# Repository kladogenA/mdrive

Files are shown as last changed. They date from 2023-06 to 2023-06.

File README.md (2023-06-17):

# mdrive
A microdrive emulator for the Sinclair QL based on Raspberry Pico and an SD card reader.

This project aims to create a standalone microdive emulator for the Sinclair QL with an OLED screen, SD card reader and buttons used to selected the MDV image to make available to the QL.
It employs a Raspberry Pico that communicates with the QL through an 74LS125 line buffer for the Tracks and diodes for the rest of the pins.
This project is in a preliminary stage, partialy working.

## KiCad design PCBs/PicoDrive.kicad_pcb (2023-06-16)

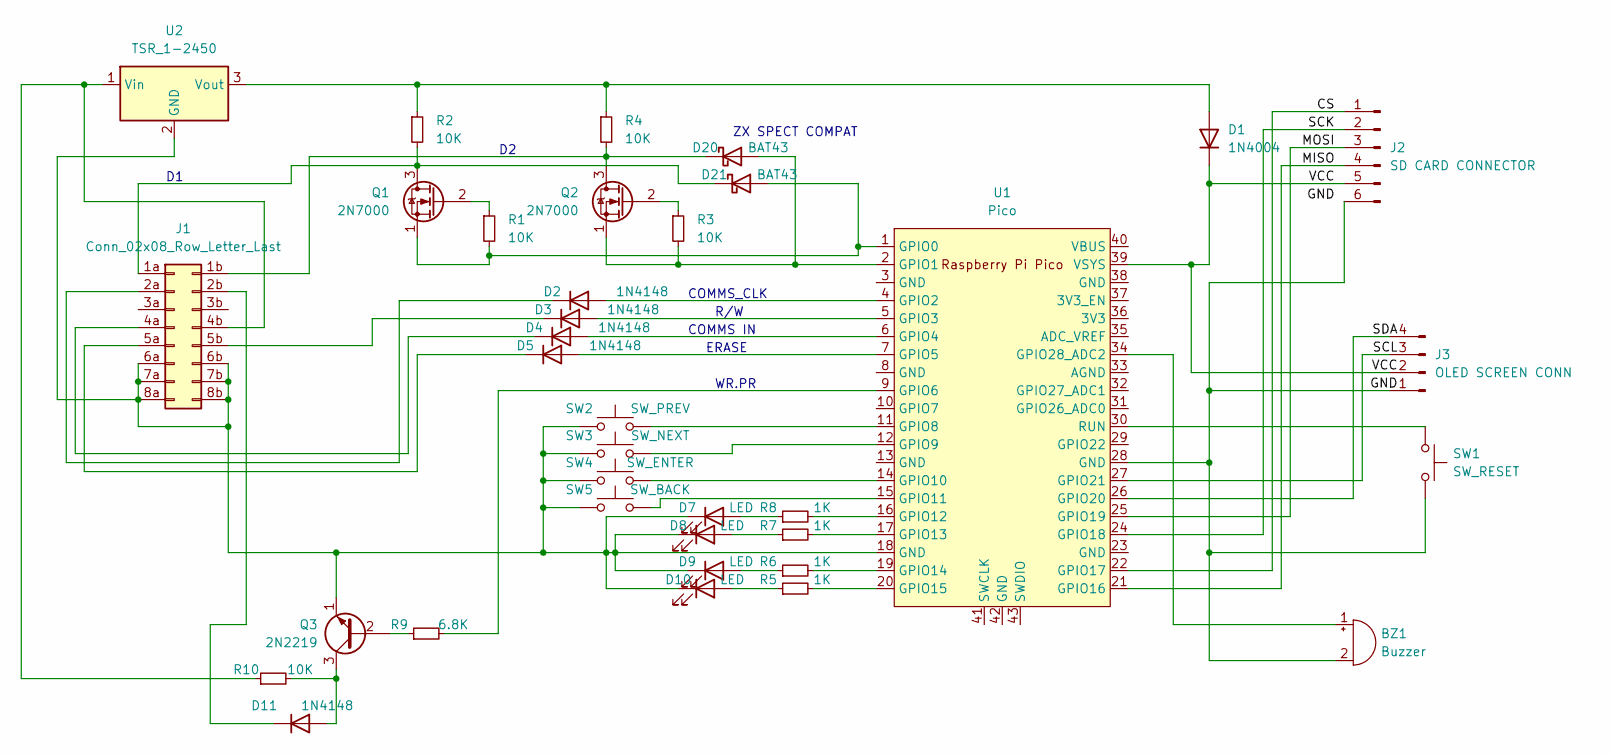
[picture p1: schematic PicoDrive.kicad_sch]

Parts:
BZ1: Buzzer; Buzzer_12x9.5RM7.6
D1: 1N4004; D_DO-41_SOD81_P10.16mm_Horizontal
D2, D3, D4, D5: 1N4148; D_DO-41_SOD81_P10.16mm_Horizontal
D7, D8, D9, D10: LED; LED_D3.0mm
D11: 1N4148; D_DO-35_SOD27_P7.62mm_Horizontal
D20, D21: BAT43; D_DO-35_SOD27_P7.62mm_Horizontal
J1: Conn_02x08_Row_Letter_Last; PinHeader_2x08_P2.54mm_Vertical_letters
J2: SD CARD CONNECTOR; PinHeader_1x06_P2.54mm_Vertical
J3: OLED SCREEN CONN; PinHeader_1x04_P2.54mm_Vertical
Q1, Q2: 2N7000; TO-92_Inline
Q3: 2N2219; TO-18-3
R1, R2, R3, R4, R10: 10K; R_Axial_DIN0204_L3.6mm_D1.6mm_P7.62mm_Horizontal
R5, R6, R7, R8: 1K; R_Axial_DIN0204_L3.6mm_D1.6mm_P7.62mm_Horizontal
R9: 6.8K; R_Axial_DIN0204_L3.6mm_D1.6mm_P7.62mm_Horizontal
SW1: SW_RESET; SW_PUSH_6mm
SW2: SW_PREV; SW_PUSH_6mm
SW3: SW_NEXT; SW_PUSH_6mm
SW4: SW_ENTER; SW_PUSH_6mm
SW5: SW_BACK; SW_PUSH_6mm
U1: Pico; RPi_Pico_SMD_TH
U2: TSR_1-2450; Converter_DCDC_TRACO_TSR-1_THT

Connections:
/CS: J2.1, U1.22 (GPIO17)
/MISO: J2.4, U1.21 (GPIO16)
/MOSI: J2.3, U1.25 (GPIO19)
/SCK: J2.2, U1.24 (GPIO18)
/VCC: D1.1 (K), J2.5, J3.2, U1.39 (VSYS)
unnamed: BZ1.1 (-), U1.34 (GPIO28_ADC2)
unnamed: D1.2 (A), R2.1, R4.1, U2.3 (Vout)
unnamed: D2.1 (K), J1.2a
unnamed: D2.2 (A), U1.4 (GPIO2)
unnamed: D3.1 (K), J1.5b
unnamed: D3.2 (A), U1.5 (GPIO3)
unnamed: D4.1 (K), J1.4a
unnamed: D4.2 (A), U1.6 (GPIO4)
unnamed: D5.1 (K), J1.5a
unnamed: D5.2 (A), U1.7 (GPIO5)
unnamed: D7.2 (A), R8.1
unnamed: D8.2 (A), R7.1
unnamed: D9.2 (A), R6.1
unnamed: D7.1 (K), D8.1 (K), D9.1 (K), D10.1 (K), J1.6a, J1.6b, J1.7a, J1.7b, J1.8a, J1.8b, Q3.1 (E), SW2.1, SW3.1, SW4.1, SW5.1, U1.18 (GND), U2.2 (GND)
unnamed: D10.2 (A), R5.1
unnamed: D11.1 (K), J1.2b
unnamed: D11.2 (A), Q3.3 (C), R10.2
unnamed: D20.1 (K), J1.1b, Q2.3 (D), R4.2
unnamed: D20.2 (A), Q2.1 (S), R3.2, U1.2 (GPIO1)
unnamed: D21.1 (K), J1.1a, Q1.3 (D), R2.2
unnamed: D21.2 (A), Q1.1 (S), R1.2, U1.1 (GPIO0)
unnamed: J1.4b, R10.1, U2.1 (Vin)
unnamed: BZ1.2 (+), J2.6, J3.1, SW1.2, U1.28 (GND)
unnamed: J3.3, U1.27 (GPIO21)
unnamed: J3.4, U1.26 (GPIO20)
unnamed: Q1.2 (G), R1.1
unnamed: Q2.2 (G), R3.1
unnamed: Q3.2 (B), R9.1
unnamed: R5.2, U1.20 (GPIO15)
unnamed: R6.2, U1.19 (GPIO14)
unnamed: R7.2, U1.17 (GPIO13)
unnamed: R8.2, U1.16 (GPIO12)
unnamed: R9.2, U1.9 (GPIO6)
unnamed: SW1.1, U1.30 (RUN)
unnamed: SW2.2, U1.11 (GPIO8)
unnamed: SW3.2, U1.12 (GPIO9)
unnamed: SW4.2, U1.14 (GPIO10)
unnamed: SW5.2, U1.15 (GPIO11)

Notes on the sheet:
R/W
ERASE
ZX SPECT COMPAT
COMMS_CLK
COMMS IN
WR.PR

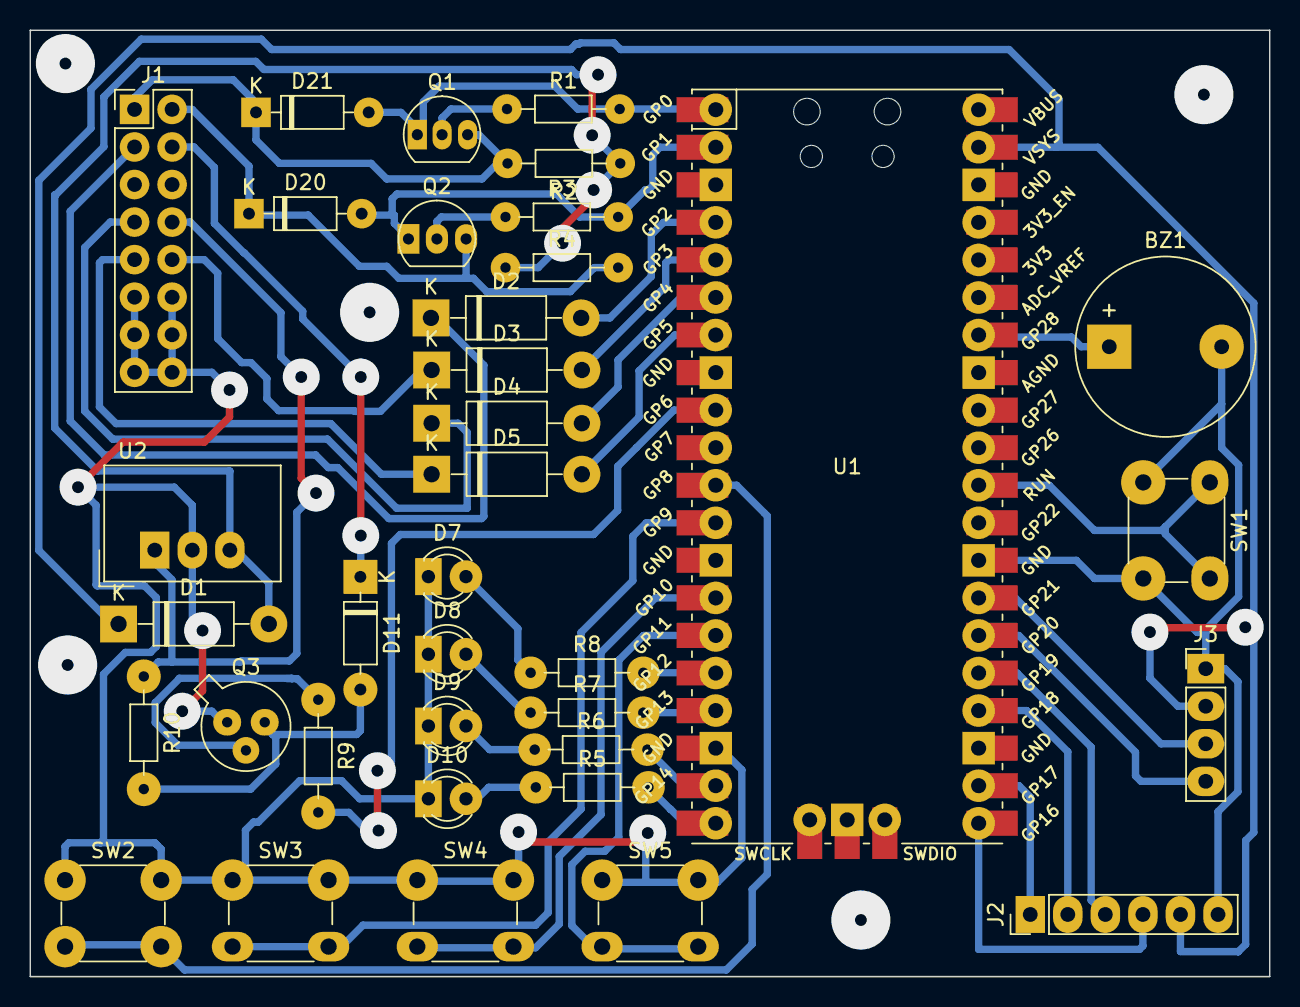
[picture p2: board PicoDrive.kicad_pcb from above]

Board: 2 copper layers, 83.8 x 64.0 mm, 36 parts (0 on the bottom side), 43 nets.

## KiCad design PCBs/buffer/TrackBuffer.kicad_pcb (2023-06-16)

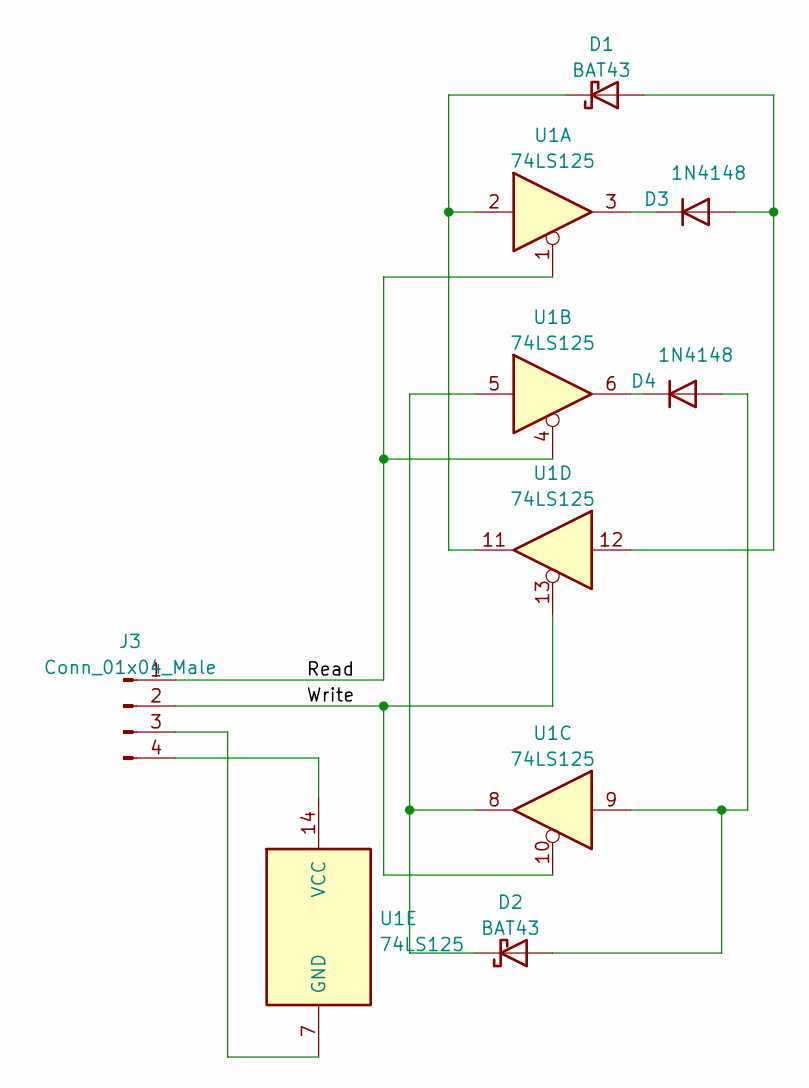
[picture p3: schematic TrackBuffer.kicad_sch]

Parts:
D1, D2: BAT43; D_DO-35_SOD27_P7.62mm_Horizontal
D3, D4: 1N4148; D_T-1_P5.08mm_Horizontal
J3: Conn_01x04_Male; PinHeader_1x04_P2.54mm_Vertical
U1: 74LS125

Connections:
/Read: J3.1, U1.1, U1.4
/Write: J3.2, U1.10, U1.13
unnamed: D2.1 (K), U1.5, U1.8
unnamed: D2.2 (A), D4.2 (A), U1.9
unnamed: D1.2 (A), D3.2 (A), U1.12
unnamed: J3.3, U1.7 (GND)
unnamed: J3.4, U1.14 (VCC)
unnamed: D3.1 (K), U1.3
unnamed: D4.1 (K), U1.6
unnamed: D1.1 (K), U1.2, U1.11

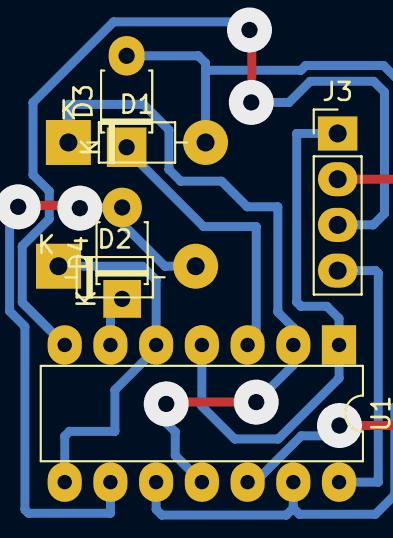
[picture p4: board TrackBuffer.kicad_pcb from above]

Board: 2 copper layers, 6 parts (0 on the bottom side), 10 nets.

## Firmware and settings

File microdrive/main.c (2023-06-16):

#include <stdio.h>
#include <stdlib.h>
#include <ctype.h>
#include "pico/stdlib.h"
#include <string.h>
#include "sd_card.h"
#include "ff.h"
#include "ff_stdio.h"

typedef unsigned char byte;

/*
1A -> GPIO0 TRACK1
1B -> GPIO1 TRACK2 
2A -> GPIO2 COMMS_CLK
2B -> GPIO6 WR.PR
3A -> NC
3B -> NC
4A -> GPIO4 COMMS_IN
4B -> U2 9V
5A -> GPIO5 ERASE
5B -> GPIO3 R/W ON TEST QL Read High is 2.2V so connected directly without voltage divider
6A -> GND
6B -> GND
7A -> GND
7B -> GNDCOMMS_CLKLED
8A -> GND
*/

#define QL_SECTOR_SIZE          686
#define QL_HEADER_SIZE          28          // 28
#define QL_BLOCK_SIZE           538         // 12 PREAMBLE + 2 HEADER + 2 CHECKSUM + 8 PREAMBLE + 512 DATA + 2 CHECKSUM = 538 DATA LENGTH
#define QL_EXTRA_DATA           86          // 84 bytes + 2 checksum

#define QL_HEADER_GAP           3590        // 3590 to get 3600μs (3.6ms)
#define QL_SECTOR_GAP           7200        // 7200μs (7.2ms) is the sector gap on oqtadrive. Why?   //5490 to get 5520μs (5.52ms)

#define SELECT_IGNORE_TIME      100         // μs

// MDV FILE SPECIFICATION 
//#define MDV_SECTOR_SIZE 0x02AE          /* 686 */
#define MDV_FILE_HEADER_SIZE 0x10       /* 16 */
#define MDV_SECTOR_HEADER_SIZE 0x28     /* 40  preamble1 12 bytes + header 16 bytes + preamble2 12 bytes = 40*/
#define MDV_PREAMBLE_SIZE 0x0C          /* 12  */
#define MDV_SECTOR_DATA_SIZE 0x21A      /* 538 524 + 2 Checksum + 12 Preamble = 538 DATA LENGTH*/
#define SECTOR_FOOTER_SIZE 0x7A         /* 122 */
#define MDV_BLOCK_SIZE     538

#define NR_ONE_BITS 8

const int PIN_BUTTON_PREVIOUS = 8;
const int PIN_BUTTON_NEXT = 9;
const int PIN_BUTTON_ENTER = 10;
const int PIN_BUTTON_BACK = 11;

const int PIN_LED_GREEN = 12;
const int PIN_LED_2 = 13;
const int PIN_LED_3 = 14;
const int PIN_LED_4 = 15;

// Use this pin to send data from the PICO to the QL
const int PIN_TRISTATE_BUFFER_QL_READ = 26; // ACTIVE LOW - Use this pin to send data from the PICO to the QL - PURPLE WIRE
const uint32_t MASK_TRISTATE_BUFFER_QL_READ = 1 << PIN_TRISTATE_BUFFER_QL_READ;

// Use this pin to send data from the QL to the PICO
const int PIN_TRISTATE_BUFFER_QL_WRITE = 27;  //  ACTIVE LOW - Use this pin to send data from the QL to the PICO - YELLOW WIRE
const uint32_t MASK_TRISTATE_BUFFER_QL_WRITE = 1 << PIN_TRISTATE_BUFFER_QL_WRITE;

const int PIN_COMMS_IN    = 4;  // 4A -> GPIO4 COMMS_IN
const int PIN_WR_PROTECT  = 6;  // 2B -> GPIO6 WR.PR 
const int PIN_COMMS_CLK   = 2;  // 2A -> GPIO2 COMMS_CLK HIGH INACTIVE on IF1, LOW on QL; interrupt 
const int PIN_ERASE       = 5;  // 5A -> GPIO5 ERASE LOW active 
const int PIN_READ_WRITE  = 3;  // 5B -> GPIO3 R/W READ is HIGH; interrupt
const int PIN_TRACK_1     = 0;  // MDV_1A 
const int PIN_TRACK_2     = 1;  // MDV_1B

const uint32_t MASK_COMMS_CLK   = 1 << PIN_COMMS_CLK;
const uint32_t MASK_COMMS_IN    = 1 << PIN_COMMS_IN;
const uint32_t MASK_WR_PROTECT  = 1 << PIN_WR_PROTECT;
const uint32_t MASK_ERASE       = 1 << PIN_ERASE;
const uint32_t MASK_READ_WRITE  = 1 << PIN_READ_WRITE;
const uint32_t MASK_TRACK_1     = 1 << PIN_TRACK_1;
const uint32_t MASK_TRACK_2     = 1 << PIN_TRACK_2;
const uint32_t MASK_BOTH_TRACKS = MASK_TRACK_1 | MASK_TRACK_2;

const int PIN_BUZZER = 28; // GPIO28

const int NumOfSectors = 255;
const int MDVFileSize = QL_SECTOR_SIZE*NumOfSectors;
char *AllSectors = NULL;

// volatile storage for MD select
volatile uint16_t reg_select;
volatile uint8_t reg_data;

void InitMDVPins(void);
int TestSDCard(void);
int InitSDCard(void);
int LoadMDV(char *fname);
int LoadSector(FF_FILE *MDVfile, char *Buff, int SectorNum);
void f_error_to_string(FRESULT f, char*message);

bool CheckButtonPressed(uint ButtonPin);
bool ButtonPrevPressed=false;
bool ButtonNextPressed=false;
bool ButtonEnterPressed=false;
bool ButtonBackPressed=false;
int WaitAndCheckButtons(int ms);

bool CheckCSum(int CalcCheckSum, byte CS1, byte CS2);
int CalcSectorCheckSum(byte *buf, int offset, int len);
int MDVCheckSum(int sum);
void HexPrint(byte *buf, int offset, int bytes_per_row, int len);
void PrintMDVSector(byte *buf);
void PrintMDVData(byte *buf);
void PrintMDVHeader(byte *buf);

// __force_inline
static bool IsQLReading(void);
static bool IsQLWriting(void);
void PinsIdle();
void PinsQLRead();
void PinsQLWrite();
void PinsDriveActiveQlRead();
void gpio_callback(uint gpio, uint32_t events) ;
volatile uint8_t SelectedDrive = 255;
volatile uint8_t ClockInCount = 0;  

bool send_bit(uint32_t tr1, uint32_t tr2);
bool send_buffer(uint8_t* buf, uint16_t offset, uint16_t len);
bool send_buffer_(uint8_t* buf, uint16_t len);
bool do_send_sector(int sector, uint8_t index);
//__force_inline static uint32_t save_and_disable_interrupts(void);
//__force_inline static void restore_interrupts(uint32_t status);

void WaitMicroseconds(uint64_t microsecs);

// FAT file system for SD card.
FATFS fs;

uint8_t mdv_index=0xff;
int main() 
{
    uint16_t old_select = 0;    

    InitMDVPins();
    PinsIdle();

    gpio_init(PIN_BUZZER);
    gpio_set_dir(PIN_BUZZER, GPIO_OUT);
    gpio_put(PIN_BUZZER, 0);

    const uint led_pid = PICO_DEFAULT_LED_PIN;
    gpio_init(led_pid);
    gpio_set_dir(led_pid, GPIO_OUT);    

    stdio_init_all();

    AllSectors = malloc(MDVFileSize);
    if(AllSectors == NULL)
    {
         printf("Failed to allocate sector memory.\n");
         while(true)
         {
            gpio_put(led_pid, 1);        
            sleep_ms(250);
            gpio_put(led_pid, 0);
            sleep_ms(250);
         }
    }
    else
    {
        memset(AllSectors, 0, MDVFileSize);
    }    

    //printf("Press any key to proceed.\r\n");
    //getchar();
    // Wait until the ENTER button is pressed
    while(!CheckButtonPressed(PIN_BUTTON_ENTER))
    {
        ;        
    }

    char fname[] = "SPACEINV.MDV";

    int time = 500;
    int res = InitSDCard();
    if(res < 0)
    {
        time = 1000;
    }
    else
    {
        res = LoadMDV(fname);
        if(res < 0)
        {
            time = (-res)*1000;
        }
    }
    //LoadMDV("SPACEINV.MDV");
/*
    int time = 500;
    int res = TestSDCard();
    if(res < 0)
    {
        time = 2000;
    }
*/
    // Print first sector (0)
    PrintMDVSector((byte *)AllSectors);
    // Print Last sector (254)
    PrintMDVSector((byte *)AllSectors+(QL_SECTOR_SIZE*(NumOfSectors-1)));

    // Start receiving interrupts from QL
    reg_select = old_select = reg_data = 0;
    gpio_set_irq_enabled_with_callback(PIN_COMMS_CLK, GPIO_IRQ_EDGE_FALL , true, &gpio_callback);
    /*
        To add more interrupt vectors use
        gpio_set_irq_enabled(22, GPIO_IRQ_EDGE_RISE | GPIO_IRQ_EDGE_FALL, true);
    */

/*
PinsQLRead();
while(1)
{    
        gpio_put(PIN_TRACK_1, 1);
        gpio_put(PIN_TRACK_2, 1);

        sleep_ms(3000);

        gpio_put(PIN_TRACK_1, 0);
        gpio_put(PIN_TRACK_2, 0);

        sleep_ms(3000);
}
*/

    int Sector=1;
    int LedState = 1;

/* Check timings*/
/*
PinsQLRead();                          
do
{
    gpio_put(PIN_LED_GREEN, LedState);                            
                            
    if(!do_send_sector(Sector, 0))
    {
        SelectedDrive = 0;
        //break;
    }
    printf("Sector:%d\r\n", Sector);
    LedState = LedState ^ 1;
                            
    Sector--;
    if(Sector==-1)
    {
        Sector=NumOfSectors-1;
    }                               
}
while (1);
*/
/* Check timings end */
    
    SelectedDrive = 0;
    if(AllSectors == NULL)
    {
        printf("Failed to allocate sector memory.\n");
    }
    else
    {
        while(1)
        {   
            
            if (SelectedDrive) 
            {
                old_select=SelectedDrive;            
                WaitMicroseconds(SELECT_IGNORE_TIME);
            }
            /*
            if(reg_select)
            {
                old_select=reg_select;            
                WaitMicroseconds(SELECT_IGNORE_TIME);
            }
            if (reg_select==old_select && reg_select>0)    
            */
            if (SelectedDrive==old_select && SelectedDrive>0)                                     
            {                    
                printf("SEL:%02x\n\r",SelectedDrive);
                gpio_put(led_pid, 1);
                /*
                mdv_index=0xff;
                
                if (old_select & 0x80) mdv_index=7;
                if (old_select & 0x40) mdv_index=6;
                if (old_select & 0x20) mdv_index=5;
                if (old_select & 0x10) mdv_index=4;
                if (old_select & 0x08) mdv_index=3;
                if (old_select & 0x04) mdv_index=2;
                if (old_select & 0x02) mdv_index=1;
                if (old_select & 0x01) mdv_index=0;                      
                //SelectedDrive = mdv_index;
                */
            //uint8_t OldSelctedDrive = 0;
                //if(mdv_index != 0xFF) 
                if(SelectedDrive > 2 && SelectedDrive<8)
                {
                    printf("Microdrive '%d' selected,\n\r",SelectedDrive);
                    // if we have a valid index
                    /*
                    if(mdv_index != 0xff)
                    {
                        printf("Microdrive '%d' selected,\n\r",mdv_index);
                    } 
                    */               
                //if(SelectedDrive > 2)
                    //if (mdv_index != 0xff && mdv_index > 2) 
                    //{
                        //OldSelctedDrive = SelectedDrive;
                        PinsQLRead();                          

                        do
                        {
                            gpio_put(PIN_LED_GREEN, LedState);                            
                            
                            if(!do_send_sector(Sector, 0))
                            {
                                SelectedDrive = 0;
                                break;
                            }
                            printf("Sector:%d\r\n", Sector);
                            LedState = LedState ^ 1;
                            
                            Sector--;
                            if(Sector==-1)
                            {
                                Sector=NumOfSectors-1;
                            } 
                              
                            /*
                            Sector++;
                            if(Sector==NumOfSectors)
                            {
                                Sector=0;
                            }
                            */
                        }
                        while (SelectedDrive == old_select);

                        // Disable output to QL through buffer
                        gpio_put(PIN_TRISTATE_BUFFER_QL_READ, 1);

                        //while (SelectedDrive==old_select); //OldSelctedDrive == SelectedDrive
                        
                        //reg_select = old_select = 0;
                        //old_select = SelectedDrive = 0;
                        PinsIdle();
                        gpio_put(led_pid, 0);
                        LedState = 0;
                        gpio_put(PIN_LED_GREEN, LedState);
                    //}   
                }  
                SelectedDrive = 0;
            }
        }        
    }

    while (true) {
        printf("Hello, world!\n");        

        gpio_put(led_pid, 1);
        gpio_put(PIN_LED_GREEN, 1);
        
        //sleep_ms(time);
        int res = WaitAndCheckButtons(time);
        if(res > 0)
        {
            if(ButtonBackPressed)
            {
                printf("Button Back Pressed\n"); 
            }
            if(ButtonEnterPressed)
            {
                printf("Button Enter Pressed\n"); 
            }
            if(ButtonNextPressed)
            {
                printf("Button Next Pressed\n"); 
            }
            if(ButtonPrevPressed)
            {
                printf("Button Prev Pressed\n"); 
            }
        }

        gpio_put(led_pid, 0);
        gpio_put(PIN_LED_GREEN, 0);
        sleep_ms(time);
        if(AllSectors == NULL)
        {
            printf("Failed to allocate sector memory.\n");
        }
    }
    return 0;
}

// inline 
static bool IsQLWriting(void)
{
    int rw = gpio_get(PIN_READ_WRITE);
    if(rw == 0)
    {
        return false;
    }
    return true;
}

// inline 
static bool IsQLReading(void)
{
    // QL switches COMMS_CLK to HIGH and keeps it HIGH as long as its interested in reading more data.
    int comms_clk = gpio_get(PIN_COMMS_CLK);
    //int rw = gpio_get(PIN_READ_WRITE);
    if(comms_clk == 1 && IsQLWriting())
    {
        return true;
    }
    return false;
}

//uint8_t InterruptCounter=0;
//uint32_t CommsINreg=0;
void gpio_callback(uint gpio, uint32_t events) 
{
    /*
    if(gpio==22)DoSomething();
    if(gpio==21)DoSomethingElse('.');
    */
   if(gpio==PIN_COMMS_CLK)
   {       
        
        int comms_in = gpio_get(PIN_COMMS_IN);
        if(comms_in == 1)
        {
            SelectedDrive = 1;            
        }
        else
        {
            SelectedDrive++;
        }
        
        /*
            ClockInCount++;
            int comms_in = gpio_get(PIN_COMMS_IN);
            if(comms_in == 1)
            {
                SelectedDrive = ClockInCount;
                ClockInCount = 0;
            }
        */  
       /*
        reg_select<<=1;
        // or in the previous data bit
        reg_select|=reg_data;
        // save current data bit
        reg_data=gpio_get(PIN_COMMS_IN);                     
        */
   }
}

void CheckOutputRegRead(void)
{
    PinsQLRead();
    gpio_put(PIN_TRACK_1, 1);
    // Read output 
    uint32_t reg = gpio_get_all();       
    // get only track bits
    uint32_t tr = reg & MASK_TRACK_1;
    if(tr == MASK_TRACK_1)
    {
        printf("TRACK 1:1\r\n");
    }
    gpio_put(PIN_TRACK_1, 0);
    // Read output
    reg = gpio_get_all();       
    // get only track bits
    tr = reg & MASK_TRACK_1;
    if((tr & MASK_TRACK_1) == 0)
    {
        printf("TRACK 1:0\r\n");
    }
    PinsIdle();
}

// send a complete sector to the QL
// during the sending the QL can pull the write line down
// to update the current sector!
bool do_send_sector(int sector, uint8_t index)
{
    bool sect_update=0;
    // myled4=0;
/*
    if(!IsQLReading())
    {
        SelectedDrive = 0;
        return false;
    }
*/
    // set pins to output
    //PinsQLRead();    

    // send the header
    //if(send_buffer((uint8_t *)AllSectors+(QL_SECTOR_SIZE*sector), 0, QL_HEADER_SIZE) == false)
    uint8_t *SectorStart = (uint8_t *)AllSectors+(QL_SECTOR_SIZE*sector);
    //if(send_buffer_((uint8_t *)(AllSectors+(QL_SECTOR_SIZE*sector)), QL_HEADER_SIZE) == false)
    if(send_buffer_(SectorStart, QL_HEADER_SIZE) == false)
    {
        return false;
    }    
    PrintMDVHeader((uint8_t *)(AllSectors+(QL_SECTOR_SIZE*sector)));

    /*
    // Wait for header gap
    headerGap = true;
    if (timerEnabled()) 
    { 
          // COMMS_CLK timer may be active at this point      
          stopTimer();
    }
    setTimer(ZX_IF1 ? TIMER_HEADER_GAP_ZX_IF1 : TIMER_HEADER_GAP_QL, endHeaderGap);      
    */

// Timing check start    
gpio_put(PIN_BUZZER, 0);
// Timing check end

    uint64_t start_t = time_us_64();
    while (start_t+QL_HEADER_GAP > time_us_64()) 
    {          
        /*
          //if (checkRecordingOrStop())         
          if(!IsReadActive())
          {
              sect_update=1;
              break;
          }          
          _delay_us(20.0);
        */
        if(!IsQLReading())
        {
            SelectedDrive = 0;
            return false;
        }
        sleep_us(10.0);
    }

// Timing check start
gpio_put(PIN_BUZZER, 1);
// Timing check end

    //send_buffer((sector_buffer+HEADER_SIZE), BLOCK_SIZE + EXTRA_BLOCK_SIZE);    
    //if(send_buffer((uint8_t *)AllSectors+(QL_SECTOR_SIZE*sector), QL_HEADER_SIZE, QL_BLOCK_SIZE) == false)

    SectorStart = SectorStart + QL_HEADER_SIZE;
    //if(send_buffer_((uint8_t *)(AllSectors+((QL_SECTOR_SIZE*sector)+QL_HEADER_SIZE)), QL_BLOCK_SIZE+QL_EXTRA_DATA) == false)
    //if(send_buffer_((uint8_t *)(AllSectors+((QL_SECTOR_SIZE*sector)+QL_HEADER_SIZE)), QL_BLOCK_SIZE) == false)
    if(send_buffer_(SectorStart, QL_BLOCK_SIZE) == false)
    {
        return false;
    }
    PrintMDVData(SectorStart);
    /*
    // check if we should rewrite this sector
    if (sect_update) {
        //MD_DATA1.input();
        //MD_DATA2.input();
        PinsWrite(); // Data flows from MDV->Nano->ESP32 thus MDV is WRITING

        // computer wants to update this sector
        // so receive the data from the QL
        do_receive();

        
        // seek to start of data block of this sector in SD card file
        //fseek(fp, (sector*MDV_SECTOR_SIZE)+HEADER_SIZE+PREAMBLE_SIZE, SEEK_SET);
        // write data block part from buffer (skip first two FF bytes)
        //fwrite(buffer+2,BLOCK_SIZE-PREAMBLE_SIZE,1,fp);
        ESP32_WriteMDVSector(index, sector, sector_buffer, MDV_SECTOR_SIZE);
        //myled4=0;
        PinsRead();
    } 
    else 
    {
        // else send data block from buffer
        send_buffer((sector_buffer+HEADER_SIZE), BLOCK_SIZE + EXTRA_BLOCK_SIZE);        
    }
    */
    // wait GAP2 time ---- AK no need for this since sector read from serial requires 6ms
    //while (LPC_CT32B0->TC < GAP2_TIME);
    start_t = time_us_64();
    while (start_t+QL_SECTOR_GAP > time_us_64()) 
    {   
        if(!IsQLReading())
        {
            SelectedDrive = 0;
            return false;
        }              
        sleep_us(20.0);
    }
                
    //PinsDriveActiveQlRead();    
    //MD_DATA1.input();
    //MD_DATA2.input();
    return true;
}

// Send a buffer full of data to the QL
bool send_buffer_(uint8_t* buf, uint16_t len)
{
    int n,m;
    //unsigned int track1=0,track2=0;
    uint8_t track1=0,track2=0;

    //noInterrupts();    
    //uint32_t inter_status = save_and_disable_interrupts();
    // send them bytes            
    n=0;
    while (n < len) 
    {
        track1 = buf[n++];
        for (m=0; m<4; m++) {
            if(send_bit(track1 & 1, track2 & 1) == false) 
            {
                // Update mode activated or not selected any more
                return false;
            }
            track1>>=1;
            track2>>=1;
        }
        //n++;
        track2 |= buf[n++];
        for (m=0; m<4; m++) {
            if(send_bit(track1 & 1, track2 & 1) == false)
            {
                // Update mode activated or not selected any more
                return false;
            }
            track1>>=1;
            track2>>=1;
        }
        //n++;
    }
    // send last bits of track 2
    for (m=0; m<4; m++) 
    {
        if(send_bit(track1 & 1, track2 & 1) == false)
        {
            // Update mode activated or not selected any more
            return false;
        }
        track1>>=1;
        track2>>=1;
    }
    
    // set idle level (high)    
    //MD_DATA1=1;
    //MD_DATA2=1;         
    gpio_put(PIN_TRACK_1, 1);
    gpio_put(PIN_TRACK_2, 1);
   
    //interrupts();
    //restore_interrupts(inter_status);
    return true;
}

// Send a buffer full of data to the QL
bool send_buffer(uint8_t* buf, uint16_t offset, uint16_t len)
{
    int n,m;
    //unsigned int track1=0,track2=0;
    uint8_t track1=0,track2=0;

    //noInterrupts();    
    //uint32_t inter_status = save_and_disable_interrupts();
    // send them bytes
    n=offset;
    uint16_t count_end = offset+len;
    
    while (n<count_end) 
    {
        track1 = buf[n];
        for (m=0; m<4; m++) {
            if(send_bit(track1 & 1, track2 & 1) == false) 
            {
                // Update mode activated or not selected any more
                return false;
            }
            track1>>=1;
            track2>>=1;
        }
        n++;
        track2 |= buf[n];
        for (m=0; m<4; m++) {
            if(send_bit(track1 & 1, track2 & 1) == false)
            {
                // Update mode activated or not selected any more
                return false;
            }
            track1>>=1;
            track2>>=1;
        }
        n++;
    }
    // send last bits of track 2
    for (m=0; m<4; m++) 
    {
        if(send_bit(track1 & 1, track2 & 1) == false)
        {
            // Update mode activated or not selected any more
            return false;
        }
        track1>>=1;
        track2>>=1;
    }
    
    // set idle level (high)    
    //MD_DATA1=1;
    //MD_DATA2=1;         
    gpio_put(PIN_TRACK_1, 1);
    gpio_put(PIN_TRACK_2, 1);
   
    //interrupts();
    //restore_interrupts(inter_status);
    return true;
}
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

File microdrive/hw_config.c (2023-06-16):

/* hw_config.c
Copyright 2021 Carl John Kugler III

Licensed under the Apache License, Version 2.0 (the License); you may not use 
this file except in compliance with the License. You may obtain a copy of the 
License at

   http://www.apache.org/licenses/LICENSE-2.0 
Unless required by applicable law or agreed to in writing, software distributed 
under the License is distributed on an AS IS BASIS, WITHOUT WARRANTIES OR 
CONDITIONS OF ANY KIND, either express or implied. See the License for the 
specific language governing permissions and limitations under the License.
*/
/*

This file should be tailored to match the hardware design.

There should be one element of the spi[] array for each hardware SPI used.

There should be one element of the sd_cards[] array for each SD card slot.
The name is should correspond to the FatFs "logical drive" identifier.
(See http://elm-chan.org/fsw/ff/doc/filename.html#vol)
The rest of the constants will depend on the type of
socket, which SPI it is driven by, and how it is wired.

*/

#include <string.h>
//
#include "my_debug.h"
//
#include "hw_config.h"
//
#include "ff.h" /* Obtains integer types */
//
#include "diskio.h" /* Declarations of disk functions */

// Hardware Configuration of SPI "objects"
// Note: multiple SD cards can be driven by one SPI if they use different slave
// selects.
static spi_t spis[] = {  // One for each SPI.
    {
        .hw_inst = spi0,  // SPI component
        .miso_gpio = 16,  // GPIO number (not pin number) (12)
        .mosi_gpio = 19,  // 15
        .sck_gpio = 18,   //14
        .baud_rate = 12500 * 1000,  
        //.baud_rate = 25 * 1000 * 1000, // Actual frequency: 20833333. 
    }
};

// Hardware Configuration of the SD Card "objects"
static sd_card_t sd_cards[] = {  // One for each SD card
    {
        .pcName = "0:",   // Name used to mount device
        .spi = &spis[0],  // Pointer to the SPI driving this card
        .ss_gpio = 17,    // The SPI slave select GPIO for this SD card (9)
        .use_card_detect = true,
        .card_detect_gpio = 13,   // Card detect (13)
        .card_detected_true = 1  // What the GPIO read returns when a card is
                                 // present. Use -1 if there is no card detect.
    }};

/* ********************************************************************** */
size_t sd_get_num() { return count_of(sd_cards); }
sd_card_t *sd_get_by_num(size_t num) {
    if (num <= sd_get_num()) {
        return &sd_cards[num];
    } else {
        return NULL;
    }
}
size_t spi_get_num() { return count_of(spis); }
spi_t *spi_get_by_num(size_t num) {
    if (num <= sd_get_num()) {
        return &spis[num];
    } else {
        return NULL;
    }
}

/* [] END OF FILE */
